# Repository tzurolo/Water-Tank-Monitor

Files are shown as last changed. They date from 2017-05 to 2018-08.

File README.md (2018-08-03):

# Water Tank Monitor
Monitors the water level in a tank that supplies the daily water to the Lion of Judah Academy campus of over 800 students.

You can see it in action with this ThingSpeak plugin: https://thingspeak.com/plugins/17358

Battery-powered IoT endpoint that posts data to a server via a cellular module.
Design goals:
1. run on batteries for **5 years**
2. post data to a server on the half hour
3. REPL over TCP/IP

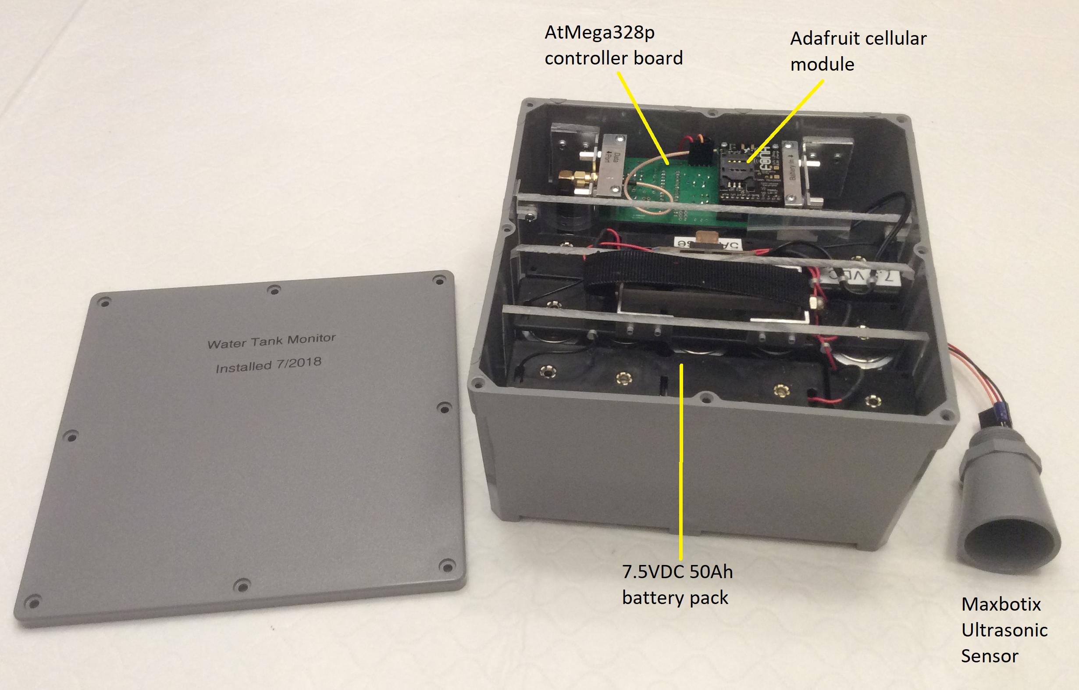
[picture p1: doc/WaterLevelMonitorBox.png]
Water Level Monitor


## System details
Water level is measured using an ultrasonic distance sensor in the roof of the tank. It measures the
distance from the top of the tank to the surface of the water.

The key to running on batteries for a long time is the ability for the system to go into deep sleep.
The water level doesn't change quickly, so the system can sleep for several minutes between readings.
Power to the ultrasonic sensor and cellular module is switched on and off by a FET under microcontroller control. These devices get no power when the unit is sleeping.

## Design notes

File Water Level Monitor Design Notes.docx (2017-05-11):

# Water Level Sensor Design Notes

## Voltage regulator efficiency experiments

Pololu 3.3V 500mA step down regulator

- No load

Input voltage | Input current
5V | 117uA
6.5V | 107uA

- With 27.5uA load (120K resistor)

Input voltage | Input current
5V | 134uA
6.5V | 123uA

- with 10.0mA load (330ohm resistor)

Input voltage | Input current
5V | 7.6mA
6.5V | 5.7mA

Pololu 5V step up/down regulator

- no load

Input voltage | Input current
5V | 61.5uA
6.7V | 58.6uA

- with 2.7mA load (MB7389 ultrasonic sensor)

Input voltage | Input current
5V | 3mA
6.7V | 2.55mA

- with 15.7mA load (330ohm resistor)

Input voltage | Input current
5V | 20mA
6.5V | 15.4mA

Pololu 3.3V step up/down regulator

- AtMega328P in sleep mode

Input voltage | Input current
4.3V | 49.6uA
5.8V | 54.2uA?
7.3V | 46.8uA

## Voltage regulation dynamic tests

Using the Pololu SLOscope the power used during SIM800 operations has been measured. Measurements were taken on the breadboard prototype.

With a 4.4V alkaline battery pack the output of the 4.1V regulator (S7V8A) to the SIM800 varies between 3.79V and 4.11V (about a 0.32V drop) with two 330uF low ESR capacitors on the input to the regulator. With only one capacitor the range is 3.66 to 4.17 (about a 0.51V drop). A manual cellular session took 0.62mAh, an automated session took 0.4mAh

5.88V alkaline battery pack. A manual cellular session took 0.41mAh. 3.8mA peripheral power off, 8.2mA peripheral power on.

7.3V 3.3mA pp off, 7.1mA pp on, manual session 0.32mAh, automated session 0.24mAh

## Hardware Design

There will be an attempt to design a general-purpose cellular data system. Load program through RJ45 jack? No. Debug console via sw serial with RJ11 jack (only need 4 pins)?

| I2C | SPI | HW UART | 3.3V | 4.1V | 5V
Water level sensor | TMP102 | | MB7389 | uC | SIM800 | MB7389
Water pressure sensor | TMP102 | SSP… | | uC | | SSP…
LED lighting ups remote monitor | TMP102? | | | uC | SIM800 | Comes from UPS
Remote GPS tracker | TMP102? | | SkyTraq | uC | SIM800 | no

### Power source

A 4.5V battery pack of 12 Alkaline D cells will supply at least 48Ah. However, the voltage range through the life of the batteries is not sufficient (See Experiment below). Instead a 7.5V battery pack will be used (3 strings of 5 D-cells in parallel). This should supply at least 40Ah.

Hydrogen gas generation in water proof battery compartments needs to be addressed as a potential safety issue to prevent the accumulation of dangerous levels of hydrogen gas within the device.

### Power Management

Power-down mode current looks like it’s less than 10uA. (7uA measured on 4/21/2017)

### Experiment: Running on 3V

An experiment powering the prototype with two AA batteries to emulate the conditions of the 4.5V battery pack when it is nearly completely drained. Alkaline batteries drain down to 0.8V.

With 3V the prototype failed to initiate an IP connection over cellular. The scope showed voltage dips that fell below minimum voltages. We may need a stronger up/down regulator for the cellular module. Currently using S7V8A (1A). May need a bigger regulator or bigger capacitors. Voltage too low to maintain serial communication with Pololu USB-to-serial module. A level shifter was needed to get the UART voltages back to an acceptable level.

As a result of this experiment the conclusion reached is that a 4.5V battery pack will not be sufficient. The voltage range at the end of the batteries’ useful life rules this out.

### AtMega328P

- run directly off 4.5V battery pack – no regulator needed. This means the power-down current will be only that which the AtMega328P uses (about 7uAh)
- run with 8MHz crystal
- 8-bit Timer0 – Software serial rx for debug console (4800 baud)
- 16-bit Timer1 - system clock and sotware serial tx for SIM800 and debug console (4800 baud)
- 8-bit Timer2 – software serial rx for SIM800
- Hardware UART Rx for ultrasonic sensor (9600 baud)
- Use power-down mode for sleep

### I/O Pin usage

PD0 – hardware UART Rx for ultrasonic sensor

PD2,PD3 – Software serial Rx/Tx for SIM800 (4800 baud)

PD4 – onkey for SIM800

PD5 – power status (not using)

PC4,PC5 - I2C for optional MCP9808 temperature sensor

PB0,PB1 – Software serial Rx/Tx for debug console (4800 baud)

PB2 – SS for SPI

PB3-PB5 SPI for pressure sensor

## Time sync with server

(Tasleep * 1000) / (Tasleep + Tadj) is the scale factor (at a particular temperature) for WDT sleep time.

When computing next sample time we need to account for the possibility that the WDT was running fast and we posted early. We want to avoid posting again right away. To address this we add ½ the sample interval to the current time before aligning. Aligning is therefore:

nextSampleT = (floor((t + (sampleInterval / 2)) / sampleInterval) + 1) * sampleInterval

Similarly, the decision to report at the current sample time is given by:

((t + (sampleInterval / 2)) % reportInterval) < sampleInterval

## Control flow

Water Level monitor task returns status that reports when it is done processing (reading sensors, posting data to server). When it is done we enter a sleep loop until the next scheduled processing time.

Initialize

Loop {

Tasks

If monitor task is done {

Finalize

Sleep until next interval

Initialize

}

}

Be sure to have timeout for registering on cell network.

Be sure to set BODLEVEL to 1.8V

## SparkFun SSOP to DIP Adapter - 8-Pin

BOB-00497

Eagle SOT-223 pkg: linear-technology-2:LT1129CST5

Use 1N4148 diode to level-shift 3V3 Rx pin of microcontroller to USB-to-serial adapter (assumes pull-up on Rx pin).

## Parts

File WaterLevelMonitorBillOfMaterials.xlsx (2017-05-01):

 |  |  |  | Water Level Sensor Bill of Materials
 | Qty per unit | Vendor Part # | Mfr. Part # | Description | Vendor | Cost | Total
 | 1 | 2213 |  | 8 MHz Crystal + 20pF capacitors | Adafruit | $0.75
 | 1 | 1946 |  | Adafruit FONA - Mini Cellular GSM Breakout uFL Version | Adafruit | $39.95
 | 15 |  |  | D-cell batteries | BatteryMart/Junction
 | 1 |  | E989N | Carlon box 8x8x4 | Home Depot | $21.98 |  | 2
 | 2 | 151116 |  | Capacitor Ceramic Disc 0.1µF 25V ±20% | Jameco | $0.15
 | 1 | 1946367 |  | 10uF electrolytic capacitor | Jameco | $0.12
 | 2 | 330740 |  | 100uF electrolytic capacitor | Jameco | $0.15
 | 1 | MB7389 | MB7389 | HRXL-MaxSonar®-WRMT™ | MaxBotix | $109.95
 | 3 | 12BH143A-GR | 12BH146-GR | Cylindrical Battery Contacts, Clips, Holders & Springs 4 D W/6" WIRE LDS | Mouser | $2.08
 | 3 | 12BH111A-GR | 12BH111A-GR | Cylindrical Battery Contacts, Clips, Holders & Springs 1"D" CELLS | Mouser | $1.22
 | 4 | 512-1N4148 | 1N4148 | 1N4148 diode | Mouser | $0.10
2 more | 4 | 647-RL81C331MDN1KX | RL81C331MDN1KX | Aluminum Organic Polymer Capacitors 330UF 16V 20% | Mouser | $0.94
 | 5 | 512-1N5233BTR |  | 6V zener 500mW | Mouser | $0.11
 | 1 | 512-NDP6020P | NDP6020P | P-Channel FET | Mouser | $1.65
 | 2 | 512-2N3904BU | 2N3904 | Fairchild Semiconductor 2N3904 BJT | Mouser | $0.17
 | 1 | 556-ATMEGA328P-PU | ATMEGA328P-PU | AtMega328P | Mouser | $1.19
 | 1 | 854 |  | Shrouded Box Header: 2×3-Pin, 0.100" (2.54 mm) Male | Pololu | $0.97
? | 1 | 2118 | S7V8A | Pololu Adjustable Step-Up/Step-Down Voltage Regulator | Pololu | $5.95
 | 1 | 2122 | S7V8F3 | Pololu 3.3V Step-Up/Step-Down Voltage Regulator | Pololu | $5.95
 | 1 | 2123 | S7V8F5 | Pololu 5V Step-Up/Step-Down Voltage Regulator | Pololu | $5.95
? | 1 | 2572 | S18V20ALV | Pololu Adjustable 4-12V Step-Up/Step-Down Voltage Regulator | Pololu | $15.95
 | 4 | 965 |  | 0.100" (2.54 mm) Breakaway Male Header: 1×40-Pin, Straight, Black | Pololu | $0.75
 | 3 | 1014 |  | 0.100" (2.54 mm) Female Header: 1x4-Pin, Straight | Pololu | $0.39
 | 1 | 965 |  | 0.100" Male Header: 1×40-Pin, Straight, Black | Pololu | $0.75
 | 2 | 2089 |  | Aluminum Standoff: 5/16" Length, 4-40 Thread, F-F (4-Pack) | Pololu | $1.59
 | 4 | 568 |  | Aluminum Standoff: 1/4" Length, 2-56 Thread, F-F (4-Pack) | Pololu | $1.49
 | 4 | 1955 |  | Machine Screw: #2-56, 1/4" Length, Phillips (25-pack) | Pololu | $0.99
 | 12 | 1960 |  | Machine Screw: #4-40, 1/4" Length, Phillips (25-pack) | Pololu | $0.99
 | 1 | PRT-07942 |  | DIP Sockets Solder Tail - 28-Pin 0.3" | Sparkfun | $0.95
 | 1 | PRT-00132 |  | RJ11 6-Pin Connector | Sparkfun | $1.25
 | 1 | PRT-00643 |  | RJ45 8-Pin Connector | Sparkfun | $1.50
 |  |  |  | Total |  | $225.93

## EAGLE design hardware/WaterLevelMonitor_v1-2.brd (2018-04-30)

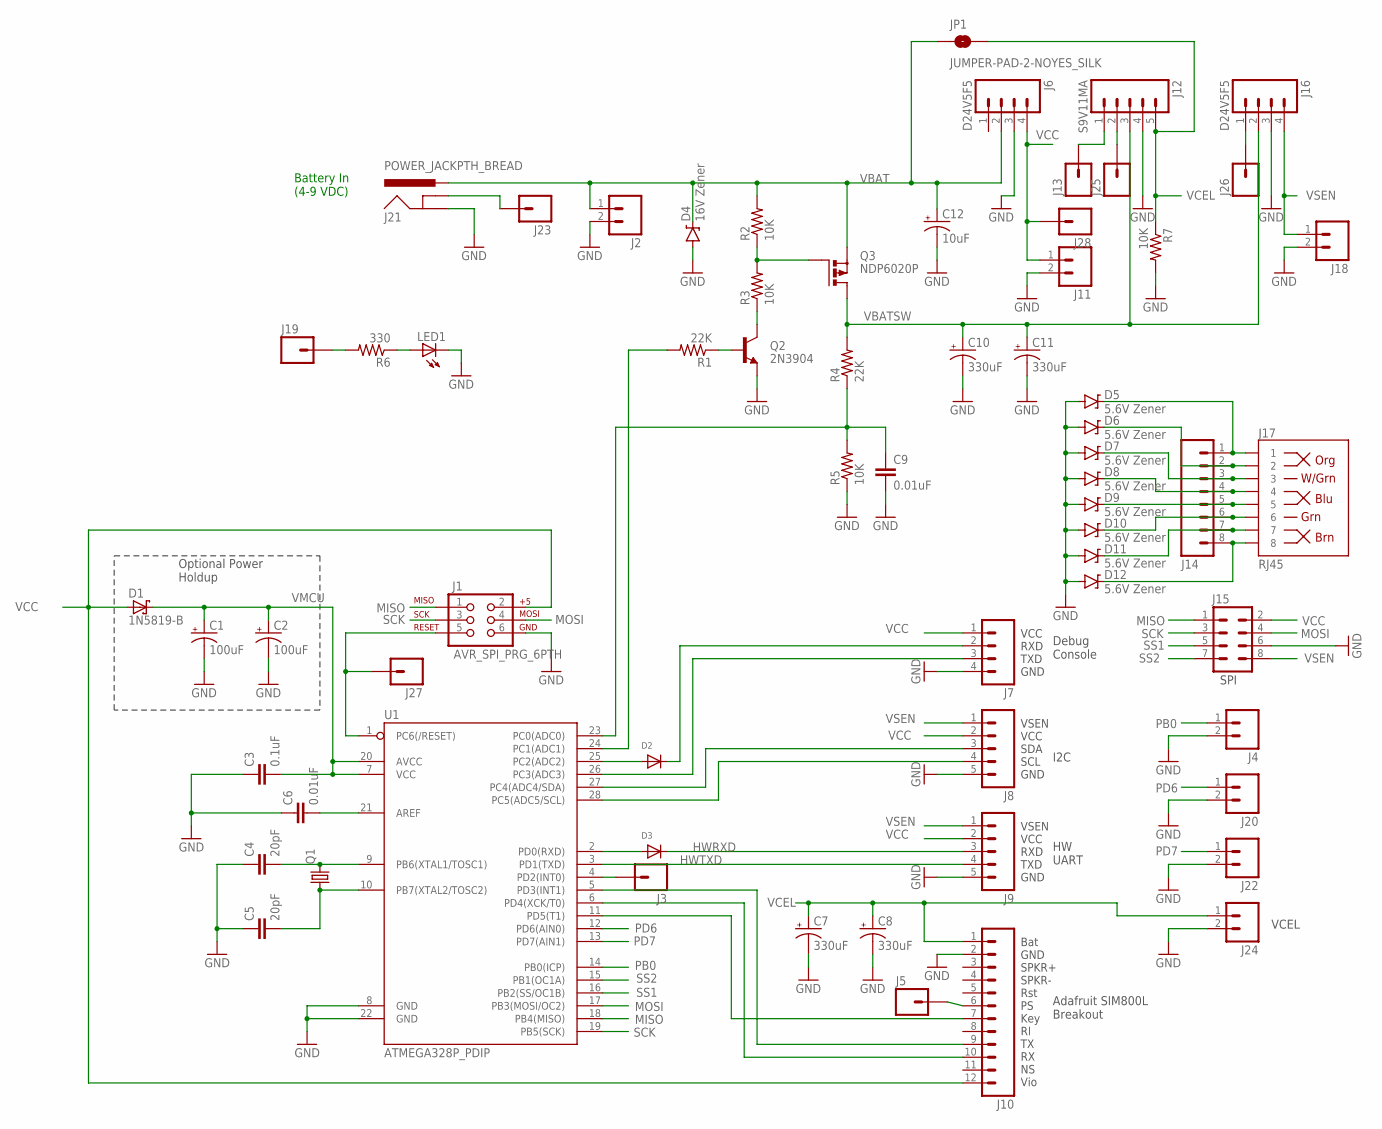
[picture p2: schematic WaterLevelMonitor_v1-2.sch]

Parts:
C1, C2: 100uF; CPOL-RADIAL-100UF-25V
C3: 0.1uF; CAP-PTH-SMALL
C4, C5: 20pF; CAP-PTH-SMALL
C6, C9: 0.01uF; CAP-PTH-5MM
C7, C8, C10, C11: 330uF; CPOL-RADIAL-100UF-25V
C12: 10uF; CPOL-RADIAL-100UF-25V
D1: 1N5819-B; DO41-7.6
D2, D3: DIODEDO-1N4148; DO-1N4148
D4: 16V Zener; DIODE-ZENER
D5, D6, D7, D8, D9, D10, D11, D12: 5.6V Zener; DIODE-ZENER
J1: AVR_SPI_PRG_6PTH; 2X3
J2, J11, J18, J24: M02PTH; 1X02
J3, J5, J13, J19, J23, J25, J26, J27, J28: M01PTH_NO_SILK_YES_STOP; 1X01_NO_SILK
J4, J20, J22: M021X02_NO_SILK; 1X02_NO_SILK
J6, J16: D24V5F5; 1X04
J7: M04PTH; 1X04
J8, J9: M05PTH; 1X05
J10: M12PTH; 1X12
J12: S9V11MA; 1X05
J14: M08SILK_FEMALE_PTH; 1X08
J15: M04X2; 2X4
J17: RJ45; RJ45-8
J21: POWER_JACKPTH_BREAD; POWER_JACK_PTH_BREAD
JP1: JUMPER-PAD-2-NOYES_SILK; PAD-JUMPER-2-NO_YES_SILK
LED1: LED5MM
Q1: CRYSTALHC49U-V; HC49U-V
Q2: 2N3904; TO-92-AMMO
Q3: NDP6020P; TO220BV
R1, R4: 22K; 0204/5
R2, R3, R5, R7: 10K; 0204/5
R6: 330; 0204/5
U1: ATMEGA328P_PDIP; DIL28-3

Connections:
GND: C1.2 (-), C2.2 (-), C3.1, C4.1, C5.1, C6.1, C7.2 (-), C8.2 (-), C9.2, C10.2 (-), C11.2 (-), C12.2 (-), D4.P$2 (A), D5.P$2 (A), D6.P$2 (A), D7.P$2 (A), D8.P$2 (A), D9.P$2 (A), D10.P$2 (A), D11.P$2 (A), D12.P$2 (A), J1.6, J2.2, J4.2, J6.3, J7.4, J8.5, J9.5, J10.2, J11.2, J12.4, J15.6, J16.3, J18.2, J20.2, J21.GND, J22.2, J24.2, LED1.K (C), Q2.1 (E), R5.1, R7.2, U1.8 (GND), U1.22 (GND)
HWRXD: D3.C, J9.3
HWTXD: J9.4, U1.3 (PD1(TXD))
MISO: J1.1, J15.1, U1.18 (PB4(MISO))
MOSI: J1.4, J15.4, U1.17 (PB3(MOSI/OC2))
unnamed: J10.7, U1.11 (PD5(T1))
unnamed: Q3.G, R2.1, R3.2
unnamed: Q2.2 (B), R1.1
unnamed: J10.9, U1.5 (PD3(INT1))
unnamed: J3.1, U1.4 (PD2(INT0))
unnamed: C9.1, R4.1, R5.2, U1.23 (PC0(ADC0))
unnamed: J10.10, U1.6 (PD4(XCK/T0))
unnamed: J19.1, R6.2
unnamed: C4.2, Q1.2, U1.9 (PB6(XTAL1/TOSC1))
unnamed: C5.2, Q1.1, U1.10 (PB7(XTAL2/TOSC2))
unnamed: C6.2, U1.21 (AREF)
unnamed: LED1.A, R6.1
unnamed: J5.1, J10.6
unnamed: Q2.3 (C), R3.1
unnamed: D3.A, U1.2 (PD0(RXD))
unnamed: J21.GNDBREAK, J23.1
unnamed: J12.2, J25.1
unnamed: J16.1, J26.1
unnamed: R1.2, U1.24 (PC1(ADC1))
unnamed: D2.A, U1.25 (PC2(ADC2))
unnamed: D2.C, J7.2
unnamed: J7.3, U1.26 (PC3(ADC3))
unnamed: D5.P$1 (C), J14.1, J17.1
unnamed: J12.1, J13.1
unnamed: J8.3, U1.27 (PC4(ADC4/SDA))
unnamed: J8.4, U1.28 (PC5(ADC5/SCL))
unnamed: D6.P$1 (C), J14.2, J17.2
unnamed: D7.P$1 (C), J14.3, J17.3
unnamed: D8.P$1 (C), J14.4, J17.4
unnamed: D9.P$1 (C), J14.5, J17.5
unnamed: J1.5, J27.1, U1.1 (PC6(/RESET))
unnamed: D10.P$1 (C), J14.6, J17.6
unnamed: D11.P$1 (C), J14.7, J17.7
unnamed: D12.P$1 (C), J14.8, J17.8
PB0: J4.1, U1.14 (PB0(ICP))
PD6: J20.1, U1.12 (PD6(AIN0))
PD7: J22.1, U1.13 (PD7(AIN1))
SCK: J1.3, J15.3, U1.19 (PB5(SCK))
SS1: J15.5, U1.16 (PB2(SS/OC1B))
SS2: J15.7, U1.15 (PB1(OC1A))
VBAT: C12.1 (+), D4.P$1 (C), J2.1, J6.2, J21.PWR, JP1.1, Q3.S, R2.2
VBATSW: C10.1 (+), C11.1 (+), J12.3, J16.2, Q3.D, R4.2
VCC: D1.A, J1.2, J6.4, J7.1, J8.2, J9.2, J10.12, J11.1, J15.2, J28.1
VCEL: C7.1 (+), C8.1 (+), J10.1, J12.5, J24.1, JP1.2, R7.1
VMCU: C1.1 (+), C2.1 (+), C3.2, D1.C, U1.7 (VCC), U1.20 (AVCC)
VSEN: J8.1, J9.1, J15.8, J16.4, J18.1

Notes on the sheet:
Battery In (4-9 VDC)
Optional Power Holdup
Adafruit SIM800L Breakout
Bat GND SPKR+ SPKR- Rst PS Key RI TX RX NS Vio
VSEN VCC SDA SCL GND
I2C
VSEN VCC RXD TXD GND
HW UART
Debug Console
VCC RXD TXD GND
SPI
VCEL

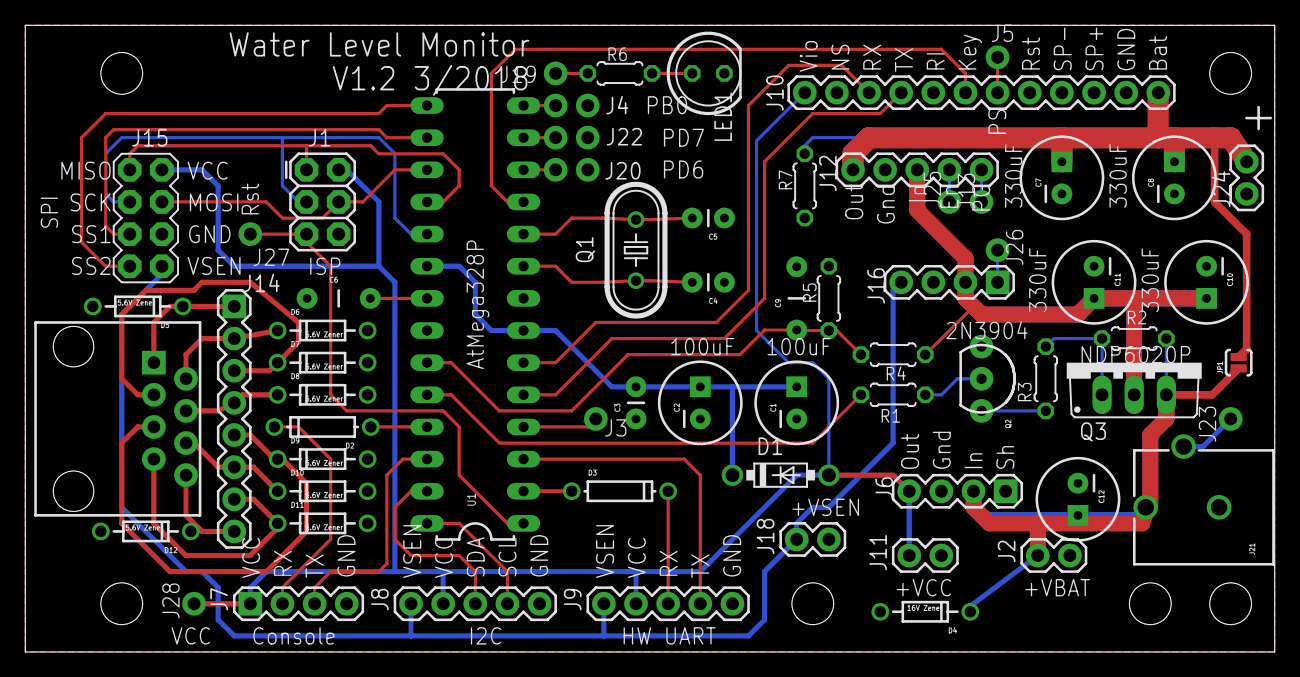
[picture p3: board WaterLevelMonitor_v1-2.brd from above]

Board: 2 copper layers, 98.7 x 49.5 mm, 71 parts (0 on the bottom side), 51 nets.

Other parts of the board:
U$1, U$2, U$3, U$4, U$5, U$6: STAND-OFF

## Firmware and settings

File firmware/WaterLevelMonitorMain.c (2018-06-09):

#include <inttypes.h>
#include <avr/io.h>
#include <avr/interrupt.h>
#include <avr/sleep.h>
#include <avr/pgmspace.h>
#include <avr/eeprom.h>
#include <avr/wdt.h>
#include <math.h>
#include <util/delay.h>
#include <avr/power.h>

#include "intlimit.h"
#include "SystemTime.h"
#include "EEPROMStorage.h"
#include "ADCManager.h"
#include "BatteryMonitor.h"
#include "Console.h"
#include "CommandProcessor.h"
#include "BatteryMonitor.h"
#include "InternalTemperatureMonitor.h"
#include "UltrasonicSensorMonitor.h"
#include "CellularComm_SIM800.h"
#include "CellularTCPIP_SIM800.h"
#include "TCPIPConsole.h"
#include "SoftwareSerialRx0.h"
#include "SoftwareSerialRx2.h"
#include "SoftwareSerialTx.h"
#include "WaterLevelMonitor.h"
#include "RAMSentinel.h"

#define WATCHDOG_TIMEOUT WDTO_500MS

static void Initialize (void)
{
    // enable watchdog timer
    wdt_enable(WATCHDOG_TIMEOUT);

    EEPROMStorage_Initialize();
    SystemTime_Initialize();
    ADCManager_Initialize();
    BatteryMonitor_Initialize();
    InternalTemperatureMonitor_Initialize();
    UltrasonicSensorMonitor_Initialize();
    SoftwareSerialRx0_Initialize();
    SoftwareSerialRx2_Initialize();
    SoftwareSerialTx_Initialize();
    Console_Initialize();
    CellularComm_Initialize();
    CellularTCPIP_Initialize();
    TCPIPConsole_Initialize();
    WaterLevelMonitor_Initialize();
    RAMSentinel_Initialize();
}
 
int main (void)
{
    Initialize();

    sei();

    for (;;) {
        if (!RAMSentinel_sentinelIntact()) {
            Console_printP(PSTR("stack collision!"));
            SystemTime_commenceShutdown();
        }

        // run all the tasks
        SystemTime_task();
        ADCManager_task();
        BatteryMonitor_task();
        InternalTemperatureMonitor_task();
        UltrasonicSensorMonitor_task();
        SIM800_task();
        Console_task();
        TCPIPConsole_task();
        CellularComm_task();
        WaterLevelMonitor_task();

        if (WaterLevelMonitor_taskIsDone() &&
            !SystemTime_shuttingDown()) {

            const uint32_t uptime = SystemTime_uptime();
            const uint32_t rebootIntervalSeconds =
                ((uint32_t)EEPROMStorage_rebootInterval()) * 60;
            if ((uptime >= rebootIntervalSeconds) &&
                !WaterLevelMonitor_hasSampleData()) {   // wait until sample data transmitted
                SystemTime_commenceShutdown();
            } else {
                // apply adjustment from server time
                SystemTime_applyTimeAdjustment();

                // disable ADC (move to ADCManager)
                ADCSRA &= ~(1 << ADEN);
                power_all_disable();
                // disable all digital inputs
                DIDR0 = 0x3F;
                DIDR1 = 3;
                // turn off all pullups
                PORTB = 0;
                PORTC = 0;
                PORTD = 0;

                // compute how long to sleep until the next sample
                const uint16_t sampleInterval = EEPROMStorage_sampleInterval();
                SystemTime_t curTime;
                SystemTime_getCurrentTime(&curTime);
                SystemTime_t nextSampleTime;
                nextSampleTime.seconds =
                    (((curTime.seconds + (sampleInterval / 2)) / sampleInterval) + 1) * sampleInterval;
                nextSampleTime.hundredths = 0;
                int32_t sec32 = SystemTime_diffSec(&nextSampleTime, &curTime);
                uint16_t sleepTime = (sec32 > 65535)
                    ? 65535
                    : (sec32 < 0)
                        ? 0
                        : ((uint16_t)sec32);

                // sleep
                SystemTime_sleepFor(sleepTime);

                // re-initialize the system
                power_all_enable();
                wdt_enable(WATCHDOG_TIMEOUT);
                ADCManager_Initialize();
                BatteryMonitor_Initialize();
                InternalTemperatureMonitor_Initialize();
                UltrasonicSensorMonitor_Initialize();
                SoftwareSerialRx0_Initialize();
                SoftwareSerialRx2_Initialize();
                Console_Initialize();
                CellularComm_Initialize();
                CellularTCPIP_Initialize();
                TCPIPConsole_Initialize();

                WaterLevelMonitor_resume();
            }
        }

#if COUNT_MAJOR_CYCLES
        ++majorCycleCounter;
#endif
    }

    return (0);
}

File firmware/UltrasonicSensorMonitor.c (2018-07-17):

//
//  Ultrasonic Sensor Monitor
//
//  Uses the AtMega328P's UART to read the serial data stream from the sensor
//
//  Pin usage:
//      PD0 Rx
//

#include "UltrasonicSensorMonitor.h"

#include "UART_async.h"
#include "SystemTime.h"
#include "CharString.h"
#include "StringUtils.h"
#include "DataHistory.h"

#define SENSOR_SAMPLES 5
#define SENSOR_INVALID_RANGE 5000

CharString_define(16, sensorDataStr);
DataHistory_define(SENSOR_SAMPLES, distanceHistory);
static uint8_t numReadingsToIgnore;

void UltrasonicSensorMonitor_Initialize (void)
{
    UART_init(true);
    UART_set_baud_rate(9600);
    DataHistory_clear(&distanceHistory);

    // ignore the first readings - they are not filtered
    numReadingsToIgnore = 5;
}

bool UltrasonicSensorMonitor_haveValidSample (void)
{
    return DataHistory_length(&distanceHistory) >= SENSOR_SAMPLES;
}

int16_t UltrasonicSensorMonitor_currentDistance (void)
{
    uint16_t avgDistance = 0;
    if (DataHistory_length(&distanceHistory) >= SENSOR_SAMPLES) {
        uint16_t minTemmp;
        uint16_t maxTemp;
        DataHistory_getStatistics(
            &distanceHistory, SENSOR_SAMPLES,
            &minTemmp, &maxTemp, &avgDistance);
    }

    return avgDistance;
}

void UltrasonicSensorMonitor_task (void)
{
    char byte;
    while (UART_read_byte(&byte)) {
        if (byte == 13) {
            // end of string. Interpret
            if ((CharString_length(&sensorDataStr) == 5) &&
                (CharString_at(&sensorDataStr, 0) == 'R')) {
                CharStringSpan_t decimalStr;
                CharStringSpan_initRight(&sensorDataStr, 1, &decimalStr);
                bool isValid = false;
                int16_t dist = 0;
                uint8_t numFracDigits = 0;
                StringUtils_scanDecimal(&decimalStr, &isValid, &dist, &numFracDigits, NULL);
                if (isValid &&
					(dist > 0) &&
					(dist < SENSOR_INVALID_RANGE)) {
                    if (numReadingsToIgnore > 0) {
                        // ignoring first readings, which are not filtered
                        --numReadingsToIgnore;
                    } else {
                        DataHistory_insertValue(dist, &distanceHistory);
                    }
                }
            }
            CharString_clear(&sensorDataStr);
        } else {
            CharString_appendC(byte, &sensorDataStr);
        }
    }
}

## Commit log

2017-05-01 added -lm switch to recover 256 bytes RAM
2017-05-11 formulas for sample and logging intervals
2017-06-27 added DC power jack
    [WaterLevelMonitor_v1.brd, WaterLevelMonitor_v1.sch]
2018-03-28 fixed Serial RX0 pin change interrupt vector
2018-04-27 fixed bug of clearing incoming command
    [WaterLevelMonitor.c]
2018-04-28 settings, etc.
    watchdog timer calibration
    periodic reboot
    command prefix for SMS messages
    setters/getters
    [CommandProcessor.c, WaterLevelMonitor.c]
2018-04-30 reboot logic, more commands
    [CommandProcessor.c]
2018-05-07 tweaks to self-reboot logic, CIPQSEND=0
    [BatteryMonitor.c, CommandProcessor.c]
2018-05-10 fixed bug in block command mode
    [WaterLevelMonitor.c]
2018-05-22 system time accuracy, bug in powerdown state
    [WaterLevelMonitor.c]
2018-06-23 CSTT username, password, rising level fix
    [CommandProcessor.c, WaterLevelMonitor.c]
2018-07-06 pump data send to ThingSpeak
2018-07-17 filter out invalid sensor readings
2018-09-17 added simple "Kalman" filtering of sensor data
2018-11-14 added bounds exception for dirty sensor

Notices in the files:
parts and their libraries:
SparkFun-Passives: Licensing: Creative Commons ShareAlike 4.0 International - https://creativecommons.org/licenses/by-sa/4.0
